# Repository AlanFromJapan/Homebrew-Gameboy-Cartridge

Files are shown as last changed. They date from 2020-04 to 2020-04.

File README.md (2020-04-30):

Homebrew-Gameboy-Cartridge
==========================

**This is my fork of the original project**

To make it work (as a 32kB cartridge): check the  manual on my website http://electrogeek.cc/gameboy%20homebrew%20cartridge.html

---

Eagle library, schematic, and board files for a Gameboy Cartridge PCB that uses a Atmel AT49F040 to replace the ROM in a Gameboy cartridge.

Based on Gerry O'Brien's work on a D.I.Y. 512Kb NINTENDO Game Boy Flash Cartridge. 
http://www.digital-circuitry.com/GameBoy.htm

This work is licensed under a Creative Commons Attribution 3.0 Unported License.

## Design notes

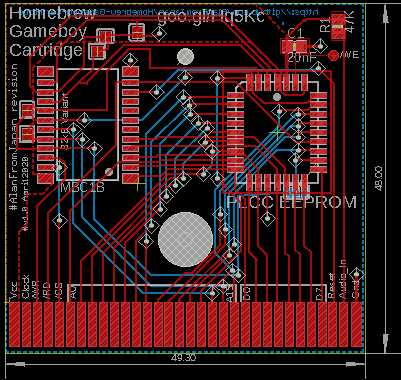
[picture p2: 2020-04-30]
homebrew gb cartridge revenge explained.png

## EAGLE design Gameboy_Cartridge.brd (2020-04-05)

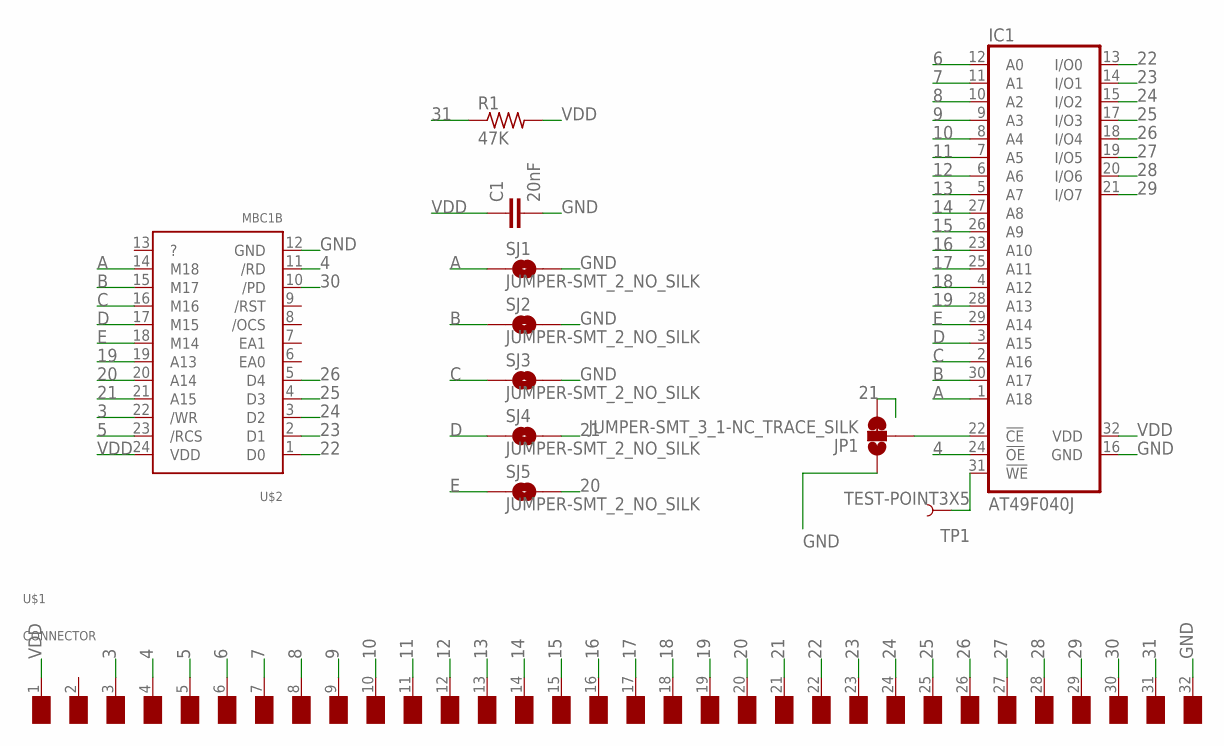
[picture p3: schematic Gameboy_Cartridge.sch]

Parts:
C1: 20nF; C0805
IC1: AT49F040J; PLCC32R
JP1: JUMPER-SMT_3_1-NC_TRACE_SILK; SMT-JUMPER_3_1-NC_TRACE_SILK
R1: 47K; M0805
SJ1, SJ2, SJ3, SJ4, SJ5: JUMPER-SMT_2_NO_SILK; SMT-JUMPER_2_NO_SILK
TP1: TEST-POINT3X5; PAD.03X.05
U$1: CONNECTOR
U$2: MBC1B

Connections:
3: U$1.3 (/WR), U$2.22 (/WR)
4: IC1.24 (!OE), U$1.4 (/RD), U$2.11 (/RD)
5: U$1.5 (/RCS), U$2.23 (/RCS)
6: IC1.12 (A0), U$1.6 (A0)
7: IC1.11 (A1), U$1.7 (A1)
8: IC1.10 (A2), U$1.8 (A2)
9: IC1.9 (A3), U$1.9 (A3)
10: IC1.8 (A4), U$1.10 (A4)
11: IC1.7 (A5), U$1.11 (A5)
12: IC1.6 (A6), U$1.12 (A6)
13: IC1.5 (A7), U$1.13 (A7)
14: IC1.27 (A8), U$1.14 (A8)
15: IC1.26 (A9), U$1.15 (A9)
16: IC1.23 (A10), U$1.16 (A10)
17: IC1.25 (A11), U$1.17 (A11)
18: IC1.4 (A12), U$1.18 (A12)
19: IC1.28 (A13), U$1.19 (A13), U$2.19 (A13)
20: SJ5.2, U$1.20 (A14), U$2.20 (A14)
21: JP1.3, SJ4.2, U$1.21 (A15), U$2.21 (A15)
22: IC1.13 (I/O0), U$1.22 (D0), U$2.1 (D0)
23: IC1.14 (I/O1), U$1.23 (D1), U$2.2 (D1)
24: IC1.15 (I/O2), U$1.24 (D2), U$2.3 (D2)
25: IC1.17 (I/O3), U$1.25 (D3), U$2.4 (D3)
26: IC1.18 (I/O4), U$1.26 (D4), U$2.5 (D4)
27: IC1.19 (I/O5), U$1.27 (D5)
28: IC1.20 (I/O6), U$1.28 (D6)
29: IC1.21 (I/O7), U$1.29 (D7)
30: U$1.30 (/RS), U$2.10 (/PD)
31: R1.1, U$1.31 (VIN)
A: IC1.1 (A18), SJ1.1, U$2.14 (M18)
B: IC1.30 (A17), SJ2.1, U$2.15 (M17)
C: IC1.2 (A16), SJ3.1, U$2.16 (M16)
D: IC1.3 (A15), SJ4.1, U$2.17 (M15)
E: IC1.29 (A14), SJ5.1, U$2.18 (M14)
GND: C1.2, IC1.16 (GND), JP1.1, SJ1.2, SJ2.2, SJ3.2, U$1.32 (GND), U$2.12 (GND)
unnamed: IC1.31 (!WE), TP1.P$1
unnamed: IC1.22 (!CE), JP1.2
VDD: C1.1, IC1.32 (VDD), R1.2, U$1.1 (VDD), U$2.24 (VDD)

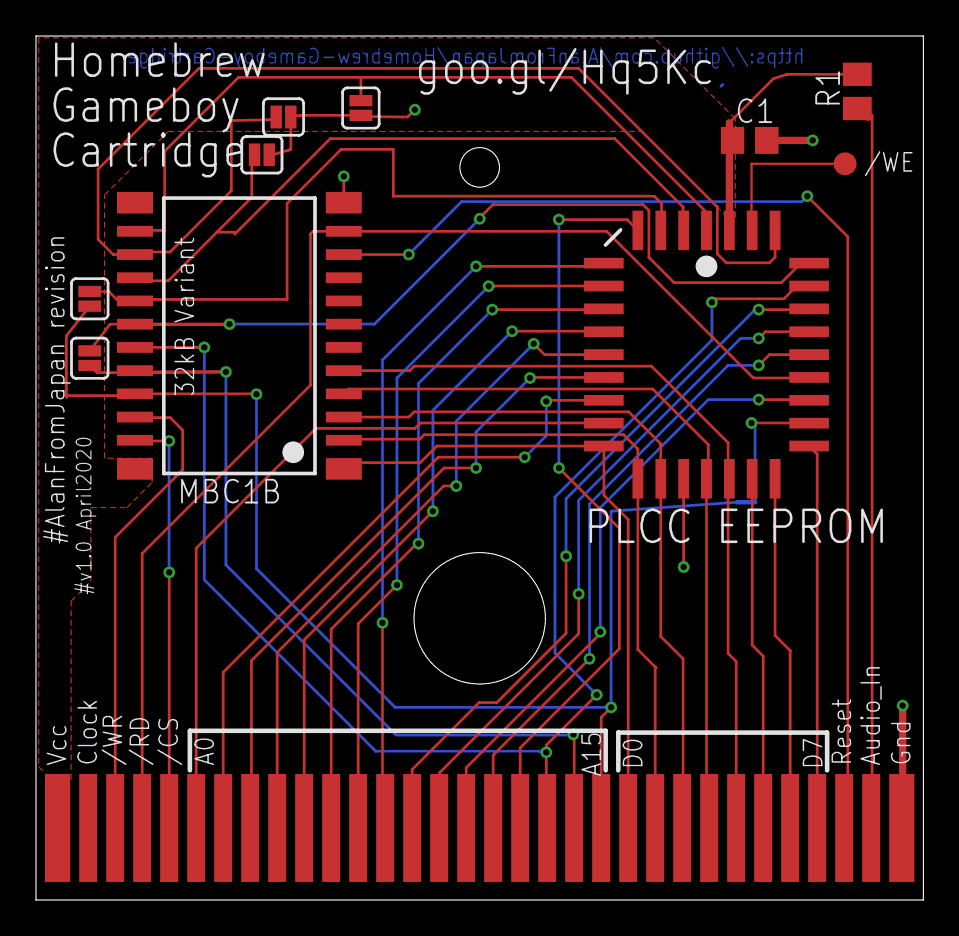
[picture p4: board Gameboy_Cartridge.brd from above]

Board: 2 copper layers, 49.3 x 48.0 mm, 12 parts (1 on the bottom side), 38 nets.

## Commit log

2020-04-04 Moved solder jumper outside of the DMG01 chip.
    [Gameboy_Cartridge.brd]
2020-04-04 Changed a few details, hope I didn't screw it up...
    [Gameboy_Cartridge.brd, Gameboy_Cartridge.sch]
2020-04-05 sent to production, hope it will work.
    [Gameboy_Cartridge.brd]

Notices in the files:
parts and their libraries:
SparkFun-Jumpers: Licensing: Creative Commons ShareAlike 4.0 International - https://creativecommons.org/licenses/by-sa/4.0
